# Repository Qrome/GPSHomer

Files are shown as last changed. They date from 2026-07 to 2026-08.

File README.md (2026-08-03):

```
   ██████╗ ██████╗ ███████╗██╗  ██╗ ██████╗ ███╗   ███╗███████╗██████╗ 
  ██╔════╝ ██╔══██╗██╔════╝██║  ██║██╔═══██╗████╗ ████║██╔════╝██╔══██╗
  ██║  ███╗██████╔╝███████╗███████║██║   ██║██╔████╔██║█████╗  ██████╔╝
  ██║   ██║██╔═══╝ ╚════██║██╔══██║██║   ██║██║╚██╔╝██║██╔══╝  ██╔══██╗
  ╚██████╔╝██║     ███████║██║  ██║╚██████╔╝██║ ╚═╝ ██║███████╗██║  ██║
   ╚═════╝ ╚═╝     ╚══════╝╚═╝  ╚═╝ ╚═════╝ ╚═╝     ╚═╝╚══════╝╚═╝  ╚═╝
```

# GPSHomer — RP2040 GPS Home Radar Display

### Hardware Quick List

- [GPSHomer Printed Circuit Board](https://www.etsy.com/listing/4545280203/) (PCB) by Qrome: https://www.etsy.com/listing/4545280203/
- Waveshare RP2040 Zero: https://amzn.to/4v0oCKq
- 1.28" Round GC9A01 TFT 240x240 LCD Display: https://amzn.to/4fnbzhy
- GPS Module: https://amzn.to/4weRRKt  

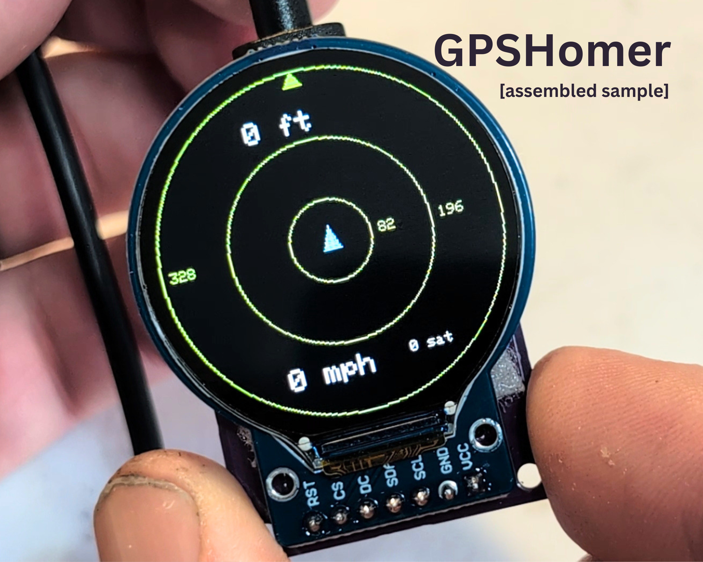
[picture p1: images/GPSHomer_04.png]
GPSHomer - Ground Radar for tracking home
 
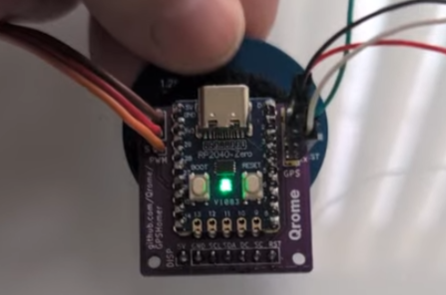
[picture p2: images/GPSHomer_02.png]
GPSHomer - Ground Radar for tracking home


## Overview
GPSHomer is a GPS‑based “Home Direction Radar” built around:

- Waveshare RP2040 Zero  
- 1.28" Round GC9A01 TFT Display (240×240, SPI)  
- NMEA GPS module (UART)

The display shows:

- Aircraft symbol (centered)
- Home direction marker (white circle with black “H”)
- **Distance from home printed next to the H marker at the top**
- (H) symbol represents home in relation to the aircraft
- Ground speed
- Satellite count
- Heading‑up radar rotation
- North indicating arrow on outer ring
- **Smooth dynamic zoom based on distance**
- **Optional distance rings (configurable)**
- Distance clamping (auto‑scaled)
- Quick double-tap to reset Home
- Single-tap to display Flight Summary
- Summary View of Flight  

Home Tracking Radar Display You Can Build - GPSHomer Detailed Build (https://www.youtube.com/watch?v=4pOJ_49xJ2c)

---
## Software & Environment Setup

This project is built for the Raspberry Pi Pico / RP2040 / RP2350 architecture using the Arduino IDE. Follow the steps below to configure your development environment.

### 1. Install the Board Support Package (BSP)
You must use the Arduino Pico core maintained by Earle F. Philhower, III. The default Arduino core will not support all features or pin mappings.

1. Open the Arduino IDE.
2. Navigate to **File** -> **Preferences**.
3. Locate the **Additional Boards Manager URLs** field and paste the following URL:
   ```text
   https://github.com/earlephilhower/arduino-pico/releases/download/global/package_rp2040_index.json
   ```
4. Click **OK**.
5. Go to **Tools** -> **Board** -> **Boards Manager...**
6. Search for `Pico` or `Philhower` and install **Raspberry Pi Pico/RP2040/RP2350** by *Earle F. Philhower, III*.
7. Once installed, go to **Tools** -> **Board** -> **Raspberry Pi Pico/RP2040** and select **Waveshare RP2040 Zero**.

### 2. Install Required Libraries
Open the Arduino Library Manager (**Tools** -> **Manage Libraries...** or press `Ctrl+Shift+I` / `Cmd+Shift+I`) to search for and install:

* **Adafruit NeoPixel** (by Adafruit)
* **TFT_eSPI** (by Bodmer)

> 💡 **Note:** When installing the libraries, if the IDE prompts you to install missing dependencies (such as `Adafruit BusIO`), choose **Install All**.
---

## Hardware

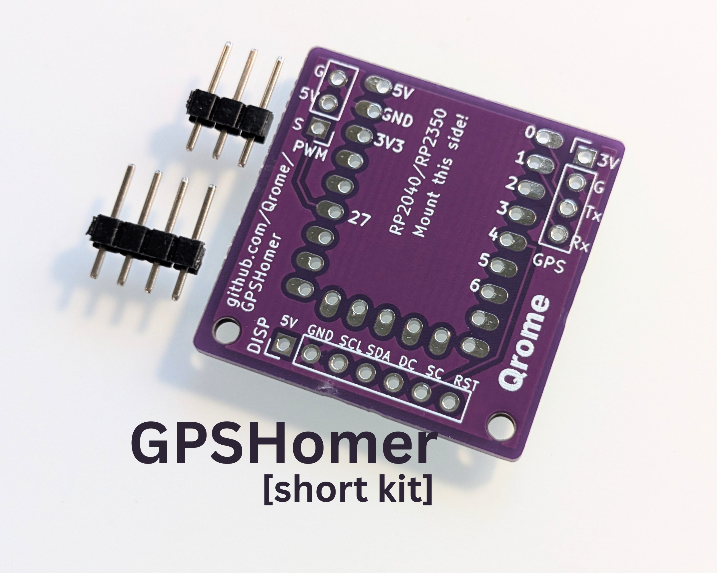
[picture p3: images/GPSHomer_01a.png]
Qrome's GPSHomer Printed Circuit Board)


### [GPSHomer Printed Circuit Board](https://www.etsy.com/listing/4545280203/) (PCB) by Qrome: https://www.etsy.com/listing/4545280203/
- Powered from 5V PWM Connection to RC Rx  
- Display Plug and Play    

### Waveshare RP2040 Zero: https://amzn.to/4v0oCKq
- Dual‑core RP2040  
- 3.3V logic  
- SPI + UART support  

### 1.28" Round GC9A01 TFT 240x240 LCD Display: https://amzn.to/4fnbzhy
- 240×240 resolution  
- 7‑wire SPI  
- GC9A01 driver  
- Pins: VCC, GND, SCL, SDA, DC, CS, RST  
- No BL pin (backlight always on)

### GPS Module: https://amzn.to/4weRRKt
- Any NMEA‑compatible GPS module  
- Baud: 9600 / 38400 / 57600 / 115200  
- Outputs GGA + RMC  
- Provides lat/lon, speed, course, fix type, satellite count  

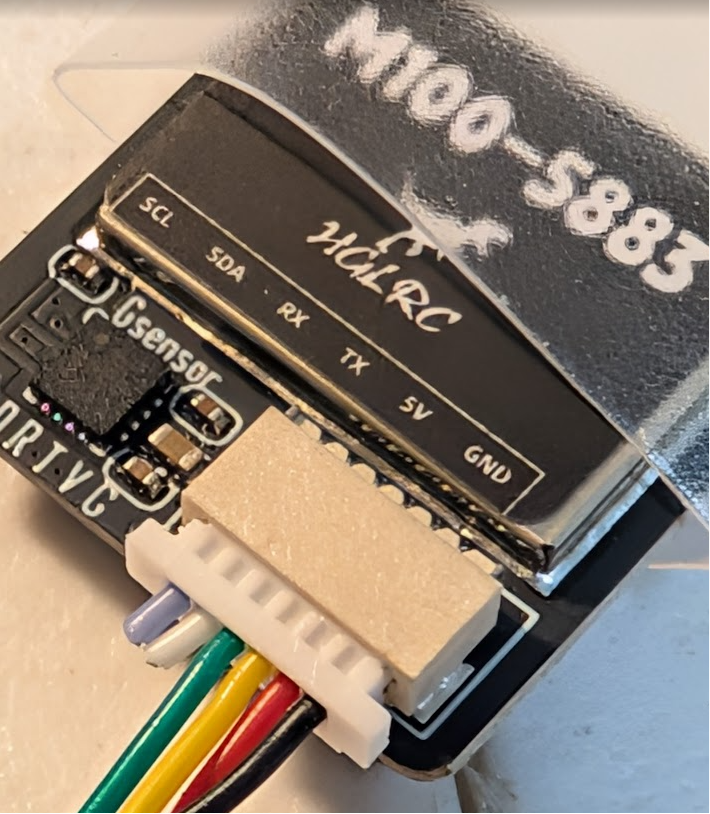
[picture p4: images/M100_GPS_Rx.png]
HGLRC M100 GPS Module

---

## Wiring

### RC RX Channel → RP2040 Zero

| PWM Pin | RP2040 Pin | Description |
|---|---|---|
| Signal  | GP27 | RC RX Ch6 → RP2040 (27)  |
| RX | 5V | 5V RX → RP2040 (5V) |
| GND | GND | Ground |

### RP2040 Zero → GC9A01 Display

| Display Pin | RP2040 Pin | Description |
|---|---|---|
| VCC | 3.3V | Power |
| GND | GND | Ground |
| SCL | GP2 | SPI Clock |
| SDA | GP3 | SPI MOSI |
| DC | GP5 | Data/Command  |
| CS | GP4 | Chip Select |
| RST | GP6 | Reset |

### RP2040 Zero → GPS Module (4 wire)

| GPS Pin | RP2040 Pin | Description |
|---|---|---|
| TX | GP1 | GPS → RP2040 (RX) |
| RX | GP0 | RP2040 → GPS (TX) |
| VCC | 3.3V | Power |
| GND | GND | Ground |

---

## TFT_eSPI Configuration (User_Setup.h)

Important details on the TFT_eSPI library and User_Setup.h -- this file 
is located next to this README.md in the the GPSHomer project.   Please 
copy it to your TFT_eSPI lbirary path -- details in comments:
```
// ============================================================================
//  GPSHomer - Custom TFT_eSPI User Setup (User_Setup.h)
// ============================================================================
//
//  IMPORTANT:
//  This file is a *project-local override* of the standard TFT_eSPI
//  configuration. It REPLACES the default User_Setup.h found in:
//
//      Documents/Arduino/libraries/TFT_eSPI/User_Setup.h
//
//  Why this file exists:
//  ----------------------
//  GPSHomer uses a GC9A01 round display and the RP2040 Zero's PIO-driven SPI.
//  The stock TFT_eSPI configuration does NOT support this hardware layout.
//  Therefore, this project provides its own User_Setup.h with the correct
//  driver, pins, and SPI mode.
//
//  Where to place this file:
//  -------------------------
//  Replace the global file:
//
//      Documents/Arduino/libraries/TFT_eSPI/User_Setup.h
//
//  Summary:
//  --------
//  * This file *must* override the default TFT_eSPI configuration.
//  * It ensures GPSHomer uses the correct GC9A01 driver + RP2040 PIO SPI.
//  * It must replace the global one.
//  * No other changes are needed once this file is in place.
```
---

## Software Architecture

### RP2040 Core 0
- Display rendering  
- Radar drawing  
- UI elements  

### RP2040 Core 1
- GPS UART reading  
- NMEA parsing  
- Updating shared navigation state  

### GPS Module
- Autodetects baud rate  
- Parses GGA + RMC  
- Tracks: lat/lon, speed, course, fix type, satellite count  

### Display Module
- Clears and redraws radar  
- Draws aircraft symbol  
- Draws home marker  
- **Draws distance from home at the top of display**
- Shows ground speed + satellite count  
- Heading‑up rotation  
- **Smooth dynamic zoom**
- **Optional distance rings**
- Flight Summary

---

## Radar Logic

- Convert lat/lon to meters  
- Compute vector from aircraft to home  
- Rotate world by negative heading  
- Compute distance  
- **Apply smooth dynamic zoom (logarithmic scaling)**  
- Clamp distance to radar radius  
- **Draw distance rings**  
- Draw home marker last  
- **Print distance from home near the top**  

---

## Configuration (config.h)

```cpp
#define OSD_UNITS        UNITS_IMPERIAL  // UNITS_METRIC or UNITS_IMPERIAL
```

---

## Project Structure

```
/
├── src
│   ├── main.ino
│   ├── Display.h
│   ├── Display.cpp
│   ├── GPS.h
│   ├── GPS.cpp
│   ├── LED.cpp
│   ├── LED.h
│   └── config.h
└── README.md
```

---

## Behavior Notes

- Home position is captured on first valid fix  
- Home position is reset by double tapping RC PWM signal low to high  
- Summary view is triggered with RC RX signal set to high  
- GPS baud autodetected at startup  
- Satellite count and ground speed shown on OSD  
- **Radar zooms smoothly based on distance**  
- **Distance rings scale dynamically**  
- **Distance printed next to home marker**  
- Home marker always drawn on top  

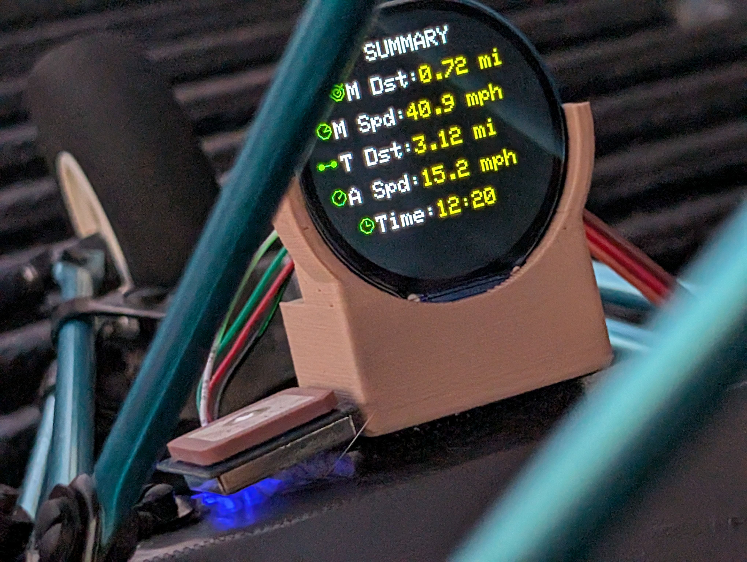
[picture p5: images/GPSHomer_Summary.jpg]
Summary View with RC RX PWM switch to high

---

GPS Homer Instrument Panel - Working Radar Style Display (https://www.youtube.com/watch?v=dhLf5rBQKtM)

## License

MIT License (or your preferred license)

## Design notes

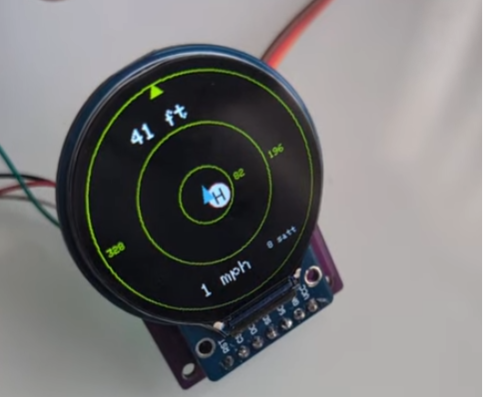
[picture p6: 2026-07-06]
images/GPSHomer_01.png

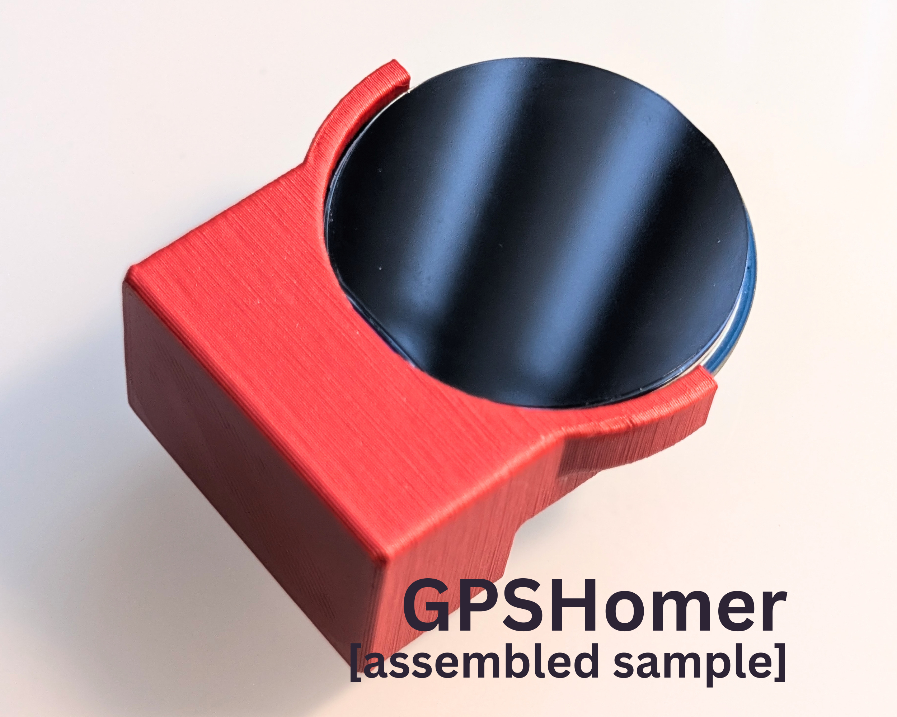
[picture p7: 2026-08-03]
images/GPSHomer_03.png

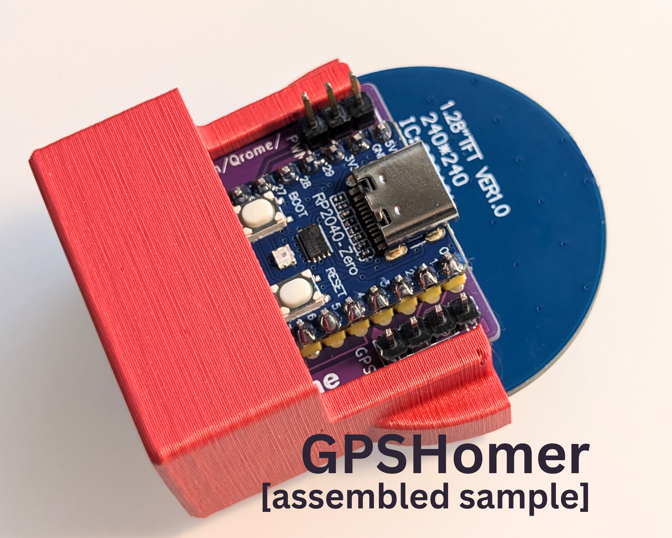
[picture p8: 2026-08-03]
images/GPSHomer_02a.png

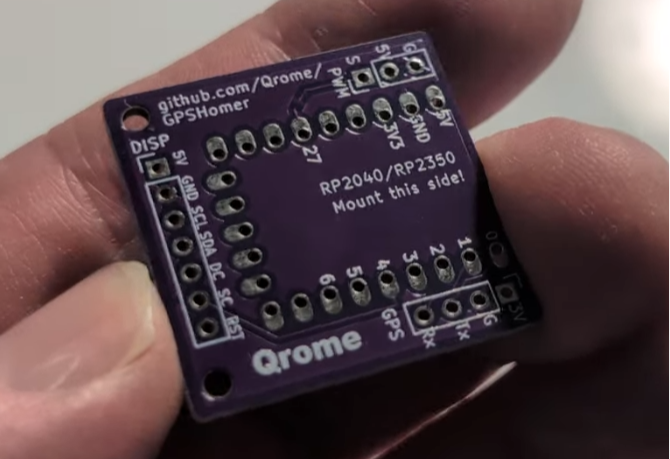
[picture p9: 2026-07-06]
images/GPSHomer_PCB.png

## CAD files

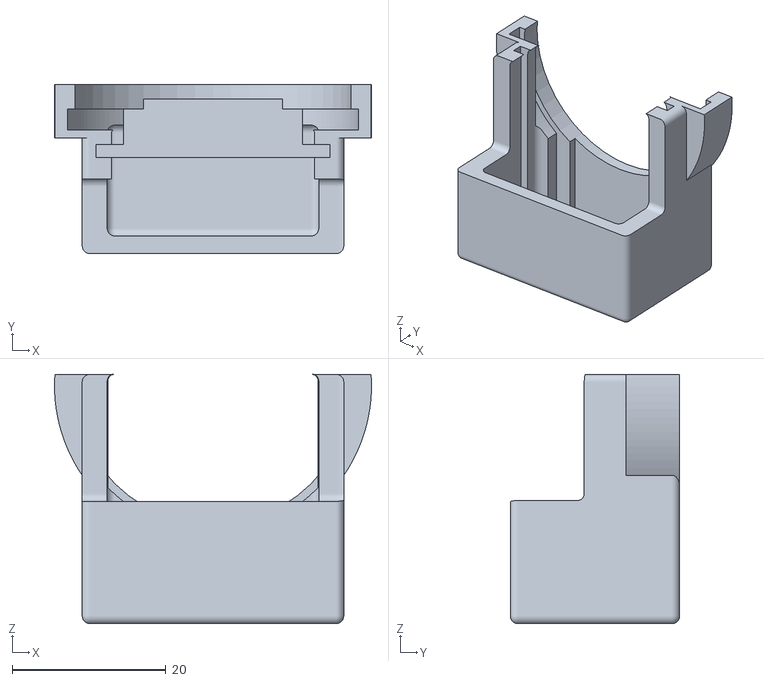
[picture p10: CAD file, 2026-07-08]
STL/GPSHomer_case.stl
41.2 x 22.0 x 32.4

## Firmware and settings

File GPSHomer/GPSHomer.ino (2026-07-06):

#include <Arduino.h>
#include "config.h"
#include "GPS.h"
#include "Display.h"
#include "LED.h"

// --- Trail storage (actual definitions) ---
#if ENABLE_TRAIL
TrailPoint g_trail[TRAIL_MAX_POINTS];
uint16_t g_trailIndex = 0;
uint16_t g_trailCount = 0;
#endif


// Shared state between cores
volatile bool  g_homeSet      = false;
volatile float g_homeLatDeg   = 0.0f;
volatile float g_homeLonDeg   = 0.0f;

volatile float g_curLatDeg    = 0.0f;
volatile float g_curLonDeg    = 0.0f;
volatile float g_speedMs      = 0.0f;
volatile float g_headingDeg   = 0.0f;
volatile uint8_t g_sats       = 0;

volatile float g_maxDistance = 0.0f;
volatile float g_maxSpeed = 0.0f;
volatile float g_totalDistance = 0.0f;
volatile float g_avgSpeed = 0.0f;
volatile uint32_t g_flightStartMs = 0;
bool g_showingSummary = false;
static float fs_lastLat = 0;
static float fs_lastLon = 0;
static bool  fs_first   = true;

GPS gps;
Display display;
StatusLED led;

uint32_t g_detectedBaud = 0;
bool g_baudReported = false;
uint32_t g_lastGpsDataMs = 0;
bool rcHighDetected = false;

void resetFlightSummary() {
    g_maxDistance = 0;
    g_maxSpeed = 0;
    g_totalDistance = 0;
    g_avgSpeed = 0;
    g_flightStartMs = millis();
#if ENABLE_TRAIL
    g_trailCount = 0;
    g_trailIndex = 0;
#endif
}

unsigned long readRcPwm() {
    unsigned long pulse = pulseIn(RC_PWM_PIN, HIGH, 25000);  // 25ms timeout

    // No signal or floating pin → return 0
    if (pulse < 900 || pulse > 2200) {
        return 0;
    }

    return pulse;
}


void checkRcResetTrigger() {
    static bool prevHigh = false;
    static unsigned long highStart = 0;
    static unsigned long lastClickTime = 0;
    static int clickCount = 0;

    unsigned long pwm = readRcPwm();
    bool pwmValid = (pwm >= 900 && pwm <= 2200);

    // ----------------------------------------------------
    // NO RC SIGNAL → disable summary mode completely
    // ----------------------------------------------------
    if (!pwmValid) {
        g_showingSummary = false;
        prevHigh = false;
        clickCount = 0;
        return;
    }

    bool isHigh = pwm > RC_THRESHOLD;
    unsigned long now = millis();

    // ----------------------------------------------------
    // SUMMARY MODE: ignore ALL click logic
    // ----------------------------------------------------
    if (g_showingSummary) {

        // Exit summary when PWM goes LOW
        if (!isHigh && prevHigh) {
            g_showingSummary = false;
            display.drawBackground();
        }

        prevHigh = isHigh;
        return;   // <<< prevents click detection
    }

    // ----------------------------------------------------
    // Detect rising edge (LOW → HIGH)
    // ----------------------------------------------------
    if (isHigh && !prevHigh) {
        highStart = now;
    }

    // ----------------------------------------------------
    // HIGH hold → enter summary mode
    // ----------------------------------------------------
    if (isHigh && (now - highStart >= RC_SUMMARY_HOLD_MS)) {
        g_showingSummary = true;

        float maxD, maxS, totD, avgS;
        uint32_t startMs;

        noInterrupts();
        maxD    = g_maxDistance;
        maxS    = g_maxSpeed;
        totD    = g_totalDistance;
        avgS    = g_avgSpeed;
        startMs = g_flightStartMs;
        interrupts();

        display.showSummary(maxD, maxS, totD, avgS, startMs);

        prevHigh = isHigh;
        return;
    }

    // ----------------------------------------------------
    // Detect falling edge (HIGH → LOW) → click detection
    // ----------------------------------------------------
    if (!isHigh && prevHigh) {

        if (now - lastClickTime <= RC_DOUBLE_TAP_WINDOW_MS) {
            clickCount++;
        } else {
            clickCount = 1;
        }

        lastClickTime = now;

        // Double tap detected → reset home
        if (clickCount == 2) {
            clickCount = 0;
            resetHomePosition();
        }
    }

    prevHigh = isHigh;
}


void resetHomePosition() {
    if (!gps.hasFix()) {
        return;   // do NOT reset home without a valid fix
    }

    // GPS library returns 1e-7 scaled integers
    int32_t lat1e7 = gps.getLatitude();
    int32_t lon1e7 = gps.getLongitude();

    float lat = lat1e7 * 1e-7f;
    float lon = lon1e7 * 1e-7f;

    // Reject invalid coordinates
    if (!isfinite(lat) || !isfinite(lon)) return;
    if (lat == 0.0f && lon == 0.0f) return;
    if (fabs(lat) > 90.0f || fabs(lon) > 180.0f) return;

    g_homeLatDeg = lat;
    g_homeLonDeg = lon;
    g_homeSet = true;

    resetFlightSummary();
    fs_first = true;
}




void updateFlightSummary(float latDeg, float lonDeg, float speedMs) {

    if (g_showingSummary) {
        return;   // freeze summary values while summary screen is active
    }

    if (!g_homeSet) {
        fs_first = true;
        return;
    }

    float dLat = (latDeg - g_homeLatDeg) * 110540.0f;
    float dLon = (lonDeg - g_homeLonDeg) * 111320.0f * cosf(latDeg * DEG_TO_RAD);
    float distM = sqrtf(dLat*dLat + dLon*dLon);

    if (distM > g_maxDistance)
        g_maxDistance = distM;

    if (speedMs > g_maxSpeed)
        g_maxSpeed = speedMs;

    if (!fs_first) {
        float dLat2 = (latDeg - fs_lastLat) * 110540.0f;
        float dLon2 = (lonDeg - fs_lastLon) * 111320.0f * cosf(latDeg * DEG_TO_RAD);
        float segment = sqrtf(dLat2*dLat2 + dLon2*dLon2);
        g_totalDistance += segment;
    }

    fs_first = false;
    fs_lastLat = latDeg;
    fs_lastLon = lonDeg;

    uint32_t elapsed = millis() - g_flightStartMs;
    if (elapsed > 0) {
        g_avgSpeed = g_totalDistance / (elapsed * 0.001f);
    }

#if ENABLE_TRAIL
    static uint32_t lastTrailMs = 0;
    uint32_t now = millis();

    // Add one point per second
    if (now - lastTrailMs >= 1000) {
        lastTrailMs = now;

        g_trail[g_trailIndex].lat = latDeg;
        g_trail[g_trailIndex].lon = lonDeg;

        g_trailIndex = (g_trailIndex + 1) % TRAIL_MAX_POINTS;
        if (g_trailCount < TRAIL_MAX_POINTS) g_trailCount++;
    }
#endif

}


void setup() {
    Serial.begin(115200);
    delay(500);

    led.begin();
    led.blue();   // Boot color

    pinMode(RC_PWM_PIN, INPUT);

    display.begin();

    // Show boot baud (will be updated once setup1 detects real baud)
    display.showBootBaud(g_detectedBaud);
    delay(BOOT_BAUD_DISPLAY_MS);
    display.drawBackground();
}


void loop() {
    static uint32_t lastFrameMs = 0;
    uint32_t now = millis();
    uint32_t frameInterval = 1000 / RADAR_DRAW_FPS;

    if (now - lastFrameMs >= frameInterval) {
        lastFrameMs = now;

        bool homeSet;
        float homeLat, homeLon, curLat, curLon, speed, heading;
        uint8_t sats;

        noInterrupts();
        homeSet = g_homeSet;
        homeLat = g_homeLatDeg;
        homeLon = g_homeLonDeg;
        curLat  = g_curLatDeg;
        curLon  = g_curLonDeg;
        speed   = g_speedMs;
        heading = g_headingDeg;
        sats    = g_sats;
        interrupts();

        checkRcResetTrigger();
        if (!g_showingSummary) {
            display.render(homeSet, homeLat, homeLon, curLat, curLon, heading, speed, sats);
        }
    }
}

// Core 1 setup
void setup1() {
    // Wait for USB Serial to be ready
    delay(5000);
    
    // Assign GPS UART pins
    Serial1.setRX(PIN_GPS_RX);
    Serial1.setTX(PIN_GPS_TX);

    // Start GPS UART
    gps.begin(Serial1);

    delay(1500); // wait for GPS to sync up

    // Baud autodetection
    g_detectedBaud = 0;

    for (size_t i = 0; i < sizeof(baudList) / sizeof(baudList[0]); i++) {
        if (gps.autodetectBaud(&baudList[i], 1, 1000)) {
            g_detectedBaud = baudList[i];
            break;
        }
        delay(500);
    }

    if (g_detectedBaud == 0) {
        g_detectedBaud = GPS_DEFAULT_BAUD;
    }

    g_lastGpsDataMs = millis();   // initialize GPS heartbeat
}


// Core 1 on RP2040 (Arduino core supports loop1)
void loop1() {
    static uint32_t lastSerial = 0;

    const uint32_t SERIAL_INTERVAL_MS = 2000;

    uint32_t now = millis();

    gps.update();

    // Track GPS communication health
    if (gps.isHealthy()) {
        g_lastGpsDataMs = now;  // GPS is talking to us

        int32_t lat1e7 = gps.getLatitude();
        int32_t lon1e7 = gps.getLongitude();

        float latDeg = lat1e7 * 1e-7f;
        float lonDeg = lon1e7 * 1e-7f;

        float speedMs = gps.getGroundSpeed() * 0.01f; // cm/s → m/s
        float headingDeg = gps.getCourse() * 0.1f;    // deg*10 → deg
        uint8_t sats = gps.getSatCount();

        // AUTO‑SET HOME ON FIRST VALID FIX
        if (!g_homeSet && gps.hasFix() && sats >= 6) {

            int32_t lat1e7 = gps.getLatitude();
            int32_t lon1e7 = gps.getLongitude();

            float lat = lat1e7 * 1e-7f;
            float lon = lon1e7 * 1e-7f;

            // Validate coordinates
            if (lat != 0.0f && lon != 0.0f &&
                isfinite(lat) && isfinite(lon) &&
                fabs(lat) <= 90.0f && fabs(lon) <= 180.0f)
            {
                led.green();
                g_homeLatDeg = lat;
                g_homeLonDeg = lon;
                g_homeSet = true;

                resetFlightSummary();
                fs_first = true;
            }
        }


        g_curLatDeg  = latDeg;
        g_curLonDeg  = lonDeg;
        g_speedMs    = speedMs;
        g_headingDeg = headingDeg;
        g_sats       = sats;

        updateFlightSummary(latDeg, lonDeg, speedMs);
    }

    // GPS communication timeout → LED amber
    if (now - g_lastGpsDataMs > 2000) {
        led.amber();
    }

    // Serial monitoring every 1 second
    if (now - lastSerial >= SERIAL_INTERVAL_MS) {
        lastSerial = now;

        Serial.print("Sats: ");
        Serial.print(g_sats);
        Serial.print(" | Fix: ");
        Serial.print(gps.hasFix() ? "YES" : "NO");
        Serial.print(" | HomeSet: ");
        Serial.print(g_homeSet ? "YES" : "NO");
        Serial.print(" | Baud: ");
        Serial.print(g_detectedBaud);
        Serial.print(" | Speed: ");
        Serial.print(g_speedMs);
        Serial.print(" | Lat: ");
        Serial.print(g_curLatDeg, 7);
        Serial.print(" | Lon: ");
        Serial.println(g_curLonDeg, 7);
    }

}

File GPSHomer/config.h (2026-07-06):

#pragma once

#define GPSHOMER_VERSION  1.0

// -----------------------------
// Units
// -----------------------------
#define UNITS_METRIC     0
#define UNITS_IMPERIAL   1

#define OSD_UNITS        UNITS_IMPERIAL  // UNITS_METRIC or UNITS_IMPERIAL

#define RC_PWM_PIN 27
#define RC_THRESHOLD 1700
#define RC_DOUBLE_TAP_WINDOW_MS 1000   // 1 second
#define RC_SUMMARY_HOLD_MS        600    // hold high to show summary

// Enable/disable breadcrumb trail on radar
#define ENABLE_TRAIL 0      // 1 = on, 0 = off
#define TRAIL_MAX_POINTS 300  // Max number of trail points

#if ENABLE_TRAIL
struct TrailPoint {
    float lat;
    float lon;
};

extern TrailPoint g_trail[TRAIL_MAX_POINTS];
extern uint16_t g_trailIndex;
extern uint16_t g_trailCount;
#endif

// -----------------------------
// Hardware Pins
// -----------------------------
#define PIN_GPS_TX      0   // UART0 TX
#define PIN_GPS_RX      1   // UART0 RX

// -----------------------------
// GPS Settings
// -----------------------------
#define GPS_DEFAULT_BAUD   115200
const uint32_t baudList[] = {115200, 9600, 38400, 57600};

// -----------------------------
// Display Settings
// -----------------------------
#define SCREEN_WIDTH       240
#define SCREEN_HEIGHT      240
#define SCREEN_CENTER_X    120
#define SCREEN_CENTER_Y    120
#define SCREEN_RADIUS      120

// Colors (TFT_eSPI style)
#define COLOR_BACKGROUND   TFT_BLACK
#define COLOR_AIRCRAFT     TFT_SKYBLUE
#define COLOR_HOME_CIRCLE  TFT_WHITE
#define COLOR_HOME_TEXT    TFT_BLACK
#define COLOR_TEXT         TFT_WHITE
#define COLOR_RING         TFT_GREENYELLOW  //0x03E0  // very dark lime green (RGB565) Darker: 0x02C0


// -----------------------------
// Radar Behavior
// -----------------------------
#define HOME_MARKER_RADIUS       12      // pixels
#define OSD_SHOW_RINGS           1      // 1 = show rings, 0 = hide rings


// -----------------------------
// Boot / UI Timing
// -----------------------------
#define BOOT_BAUD_DISPLAY_MS   3000
#define RADAR_DRAW_FPS         20      // target FPS

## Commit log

2026-06-06 added summary page and home reset on double tap
    [GPSHomer.ino, config.h]
2026-07-06 Updated to correct versions
    [GPS.cpp, GPSHomer.ino, config.h]
2026-07-08 added stl file
    [GPSHomer_case.stl]
2026-07-28 updated readme with the PCB link
